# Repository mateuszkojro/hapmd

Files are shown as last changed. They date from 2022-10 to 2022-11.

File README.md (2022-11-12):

# hapmd
Horizontal antenna pattern measurement device

# The logic representation of HAPMD 


# [Mocked output from HAPMD](doc/2022_11_07_10_24_30_apm_plot.pdf)

# Repository contains:
  - 3d models of 
    - rotor under Transmitter
    - silent chamber
    with documentation how to print and assemble parts
  - list of components easily obtainable ih every hardware store 
  - Arduino-Pc connector package; script controlling rotation of Transmiter
  - Script synchronizing actions of Hameg device and Arduino
  - Result visualizer
  - Documentation with how to perform
    - Repository set-up
    - Physical parts of device set-up
    - Run the experiment
    - Analyze and interpret results

# Suppliers of components:
  ### rs components
  ### farnel
  ### conrad 
  ### botland

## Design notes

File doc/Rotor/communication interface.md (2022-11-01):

# Communication standard between Python API and C++ arduino software
| *command* | *shorthand* | *arguments* | *answer* | *response time* | *example* | *description* |
|:---:|:---:|:---:|:---:|:---:|:---:|:---:|
| get angle | get | --- |  float | short | req:'get'  resp:'-12.2' | angle hold by rotor |
| set angle | set | float |  float | long | req:'set-12.4'  resp:'-12.2' | the actual motor might not be able to turn to requested angle, the true angle set by rotor is returned |
| connection status | con | --- | str | short | req:'con'  resp:'ok' | check connection state |
|  override angle | ovr | float |  float | short |  req:'ovr12.3'  resp:'12.3'  | override angle in rotor memory |

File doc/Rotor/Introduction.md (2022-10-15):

# Rotor 
Simple device driven by arduino board, enables ether transmitter or receiver to be rotated around it's center of rotation. The goal of rotor is to rotate antenna with great precision, and repeatability. The speed of rotation does not matter, neither does time to response, error tolerance is around 1°.

Biggest obstacles when designing the rotor shaft are:
- concentric cable to witch antenna is connected, this cable is not flexible thus presents big resistance when antena is turned against it. This resistance is multiplied by height of rotor shaft.
- slack between parts

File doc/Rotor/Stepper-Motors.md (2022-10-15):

# Stepper motors

A stepper motor consists of two main parts, a rotor and a stator. The rotor is the part of the motor that actually spins and provides work. The stator is the stationary part of the motor that houses the rotor. In a stepper motor, the rotor is a permanent magnet. The stator consists of multiple coils that act as electromagnets when an electrical current is passed through them. The electromagnetic coil will cause the rotor to align with it when charged. The rotor is propelled by alternating which coil has a current running through it. 

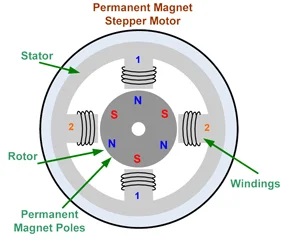
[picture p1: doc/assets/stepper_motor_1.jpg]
stepper_motor


When there is no current send to the motor, the steppers firmly hold their position. Stepper motors can also rotate without limits and change direction based on the polarity provided.

Most stepper motors come with four or six wires, stepper motors have tow coils ie, two circuits that makes 4 wires, additional two are connected to centers of the coils, therefore can be omitted. 

# Two unnecessary wires

Provided unnamed steper motors are 6-wire ones, since additional "center of the coil" wires are not needed there's a need to figure out witch is witch.

Between the wires connected to the same phase slight resistance is present, we can use that to label wires connected to same circuits. 
Between "middle of the col" wire and rest of the same circuit wires resistance will be smaller than  between other two. 

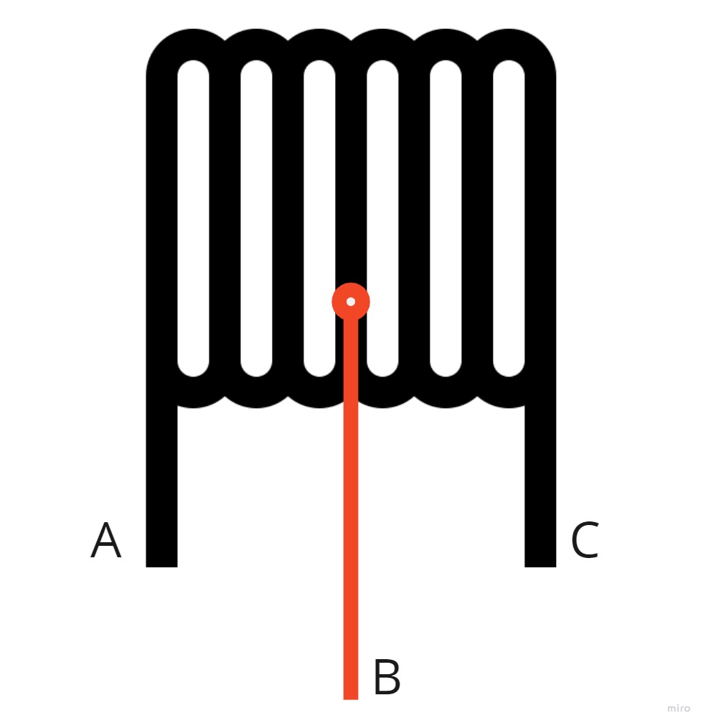
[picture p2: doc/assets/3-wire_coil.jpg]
3-wire-coil


Resistance present between wires A-C will be than between A-B or B-C, therefore wire B is the unnecessary "middle of the coil" wire.

Unnamed steper motors have 6 wires, left to right:
| Id | Color  | Abbreviation | Phase |  Function |
|:--:|:---:|:---:|:-----:|:---:|
| 1  | Orange | O | B |  End wire |
| 2  | White  | W | A | Middle Wire |
| 3  | Yellow | Y | A |  End wire |
| 4  | Brown  | Br | B |  End wire |
| 5  | Black  | Bl | B | Middle Wire |
| 6  |  Red | R | A |  End wire |

Resistances between each of them in [MΩ]:

| wire\wire | O  | W | Y  | Br | Bl | R  |
|:---:|:--:|:-:|:--:|:--:|:--:|:--:|
| O | 0  | - | -  | 15 | 9  | -  |
| W | -  | 0 | 9  | -  | -  | 9  |
| Y | -  | 9 | 0  | -  | -  | 15 |
| Br | 15 | - | -  | 0  | 9  | -  |
| Bl | 9  | - | -  | 9  | 0  | -  |
| R | -  | 9 | 15 | -  | -  | 0  |

# A4988 Driver

[Official Documentation](https://www.pololu.com/file/0J450/a4988_DMOS_microstepping_driver_with_translator.pdf)

## Pin design:

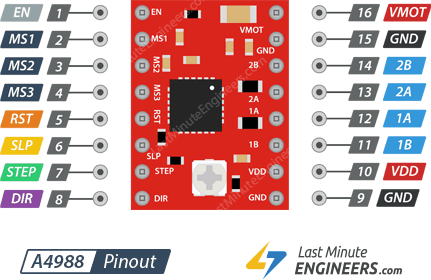
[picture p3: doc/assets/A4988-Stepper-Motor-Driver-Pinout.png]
pin_design


## Pin Modes 
| J1 | Pin  | Mode | J2 | Pin  | Mode |
|:--:|:----:|:---:|:--:|:----:|:---:|
| 1  |  EN  | Enable | 16 | VMOT | Power Voltage |
| 2  | MS1  | Micro-step setting | 15 | GND  | Ground |
| 3  | MS2  | Micro-step setting | 14 |  2B  | Phase B |
| 4  | MS3  | Micro-step setting | 13 |  2A  | Phase A |
| 5  | RST  | Reset | 12 |  1A  | Phase A |
| 6  | SLP  | Sleep | 11 |  1B  | Phase B |
| 7  | STEP | Step | 10 | VDD  | Logic voltage |
| 8  | DIR  |  Direction input | 9  | GND  | Ground |

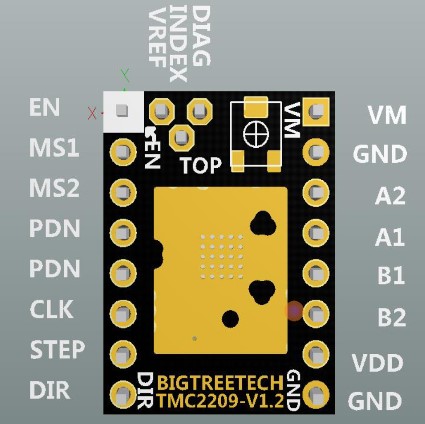
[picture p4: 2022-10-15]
doc/assets/TMC2209_pin_design.jpg

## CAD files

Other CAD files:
models/Antennas_YnVzaW5lc3M6bXllZHU2MTk2IzIwMjIwNzI3NTQyNDQ1OTA2/Bottom corner_c5e7e790-342b-49d1-b435-a4cb2366abbe.f3d
models/Antennas_YnVzaW5lc3M6bXllZHU2MTk2IzIwMjIwNzI3NTQyNDQ1OTA2/Full Box Assembly_c8e0fb49-985c-4273-afc7-069acc2b1639.f3d
models/Antennas_YnVzaW5lc3M6bXllZHU2MTk2IzIwMjIwNzI3NTQyNDQ1OTA2/Nail_13ead31a-0b00-4445-9a30-be61a9d9af6d.f3d
models/Antennas_YnVzaW5lc3M6bXllZHU2MTk2IzIwMjIwNzI3NTQyNDQ1OTA2/Rod_Stand_antenna_holder_0a369a4e-08f0-4d4c-95f8-d1debb118e1a.f3d
models/Antennas_YnVzaW5lc3M6bXllZHU2MTk2IzIwMjIwNzI3NTQyNDQ1OTA2/Rotor Shaft_825ccad0-c9c1-482b-9b45-a1c8e1959537.f3d
models/Antennas_YnVzaW5lc3M6bXllZHU2MTk2IzIwMjIwNzI3NTQyNDQ1OTA2/Stator_e84299ef-5bad-46b8-848a-41ee6117f2a9.f3d
models/Antennas_YnVzaW5lc3M6bXllZHU2MTk2IzIwMjIwNzI3NTQyNDQ1OTA2/Top corner_ed42d94d-94fe-402c-95f1-07cb350324a0.f3d
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

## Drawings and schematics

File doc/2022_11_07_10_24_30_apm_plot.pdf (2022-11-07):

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

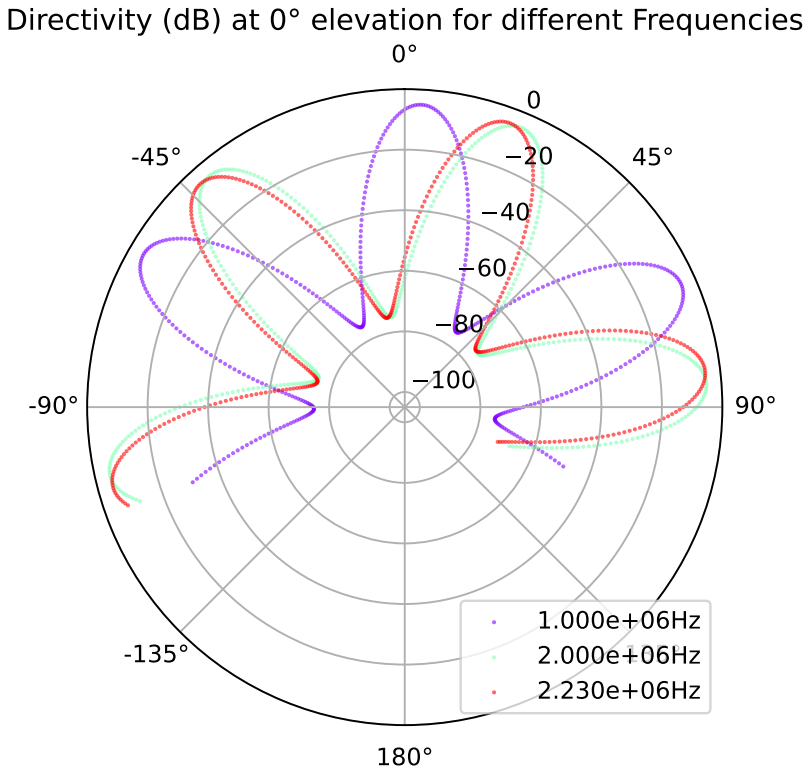
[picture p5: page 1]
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

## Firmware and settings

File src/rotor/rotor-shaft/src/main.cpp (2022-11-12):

// #include <Arduino.h>
// #include "A4988.h"

// float step_angle = 360.f / 200.f; // default change in angle, when rotated by one step
// float current_angle = 0;
// A4988 stepper_motor(6, 8);
// String response;
// String message;
// String command;
// String message_copy;
// String handle_set(const String &message)
// {
//   auto new_angle = message.toFloat();
//   int no_steps_to_move = round((new_angle - current_angle) / step_angle);
//   if (no_steps_to_move < 0)
//   {
//     stepper_motor.SetDirection(A4988::Direction::CCW);
//   }
//   else
//   {
//     stepper_motor.SetDirection(A4988::Direction::CW);
//   }
//   stepper_motor.Step(abs(no_steps_to_move));

//   current_angle = current_angle + (no_steps_to_move * step_angle);

//   return String(no_steps_to_move);
// }
// void setup()
// {
//   Serial.begin(115200);
//   Serial.print("arduino_ok\n");
// }
// void loop()
// {
//   message = Serial.readStringUntil('\n');
//   while (message.length() == 0)
//   {
//     message = Serial.readStringUntil('\n');
//     message.trim(); // deletes all leading and trailing whitespaces
//     message.replace("\n", "");
//   }

//   message_copy = message;

//   command = message.substring(0, 3);

//   if (command == "get")
//   {
//     response = String(current_angle) + "";
//   }
//   else if (command == "set")
//   {
//     response = handle_set(message.substring(3));
//   }
//   else if (command == "con")
//   {
//     response = "arduino_ok";
//   }
//   else if (command == "ovr")
//   {
//     current_angle = message.toFloat();
//     response = String(current_angle);
//   }
//   else
//   {
//     response = String("failed to intepret the input>" + message_copy + "<");
//   }
//   Serial.print(response + "\n");
// }

#include <Arduino.h>
const int dirPin = 8;
const int stepPin = 6;
const int stepsPerRevolution = 200;

void setup()
{
  // Declare pins as Outputs
  pinMode(stepPin, OUTPUT);
  pinMode(dirPin, OUTPUT);
}
void loop()
{
  // Set motor direction clockwise
  digitalWrite(dirPin, HIGH);

  // Spin motor slowly
  for (int x = 0; x < stepsPerRevolution; x++)
  {
    digitalWrite(stepPin, HIGH);
    delayMicroseconds(2000);
    digitalWrite(stepPin, LOW);
    delayMicroseconds(2000);
  }
  delay(1000); // Wait a second

  // Set motor direction counterclockwise
  digitalWrite(dirPin, LOW);

  // Spin motor quickly
  for (int x = 0; x < stepsPerRevolution; x++)
  {
    digitalWrite(stepPin, HIGH);
    delayMicroseconds(1000);
    digitalWrite(stepPin, LOW);
    delayMicroseconds(1000);
  }
  delay(1000); // Wait a second
}

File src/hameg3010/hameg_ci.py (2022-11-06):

from typing import Union
from device import Device
from device_mock import DeviceMock

def hameg_console_loop(hameg_handle:Union[Device,DeviceMock]):
    while True:
        command = input("hameg> ")
        command = command.casefold()
        command = command.replace(" ","")
        if command in ("quit", 'q'):
            return
        else:
            resp = hameg_handle.send_await_resp(command)
            print(f"response: {resp[1]}")
            print(
                f"errors:   {hameg_handle.send_await_resp('SYSTem:ERRor:ALL?')[1][2:-1]}"
            )
            
if __name__ == "__main__":
    print(
        """
        
 /$$   /$$                                                    /$$$$$$  /$$$$$$
| $$  | $$                                                   /$$__  $$|_  $$_/
| $$  | $$  /$$$$$$  /$$$$$$/$$$$   /$$$$$$   /$$$$$$       | $$  \__/  | $$  
| $$$$$$$$ |____  $$| $$_  $$_  $$ /$$__  $$ /$$__  $$      | $$        | $$  
| $$__  $$  /$$$$$$$| $$ \ $$ \ $$| $$$$$$$$| $$  \ $$      | $$        | $$  
| $$  | $$ /$$__  $$| $$ | $$ | $$| $$_____/| $$  | $$      | $$    $$  | $$  
| $$  | $$|  $$$$$$$| $$ | $$ | $$|  $$$$$$$|  $$$$$$$      |  $$$$$$/ /$$$$$$
|__/  |__/ \_______/|__/ |__/ |__/ \_______/ \____  $$       \______/ |______/
                                             /$$  \ $$                        
                                            |  $$$$$$/                        
                                             \______/                         """
    )

    hameg_device_handle = DeviceMock.connect_using_vid_pid(
        idVendor=0x0403, idProduct=0xED72
    )

    print(
        f"""
Connected to Hameg device
IDN              : {hameg_device_handle.send_await_resp("*IDN?")[1][2:-1]}
Software Version : {hameg_device_handle.send_await_resp("SYSTem:SOFTware?")[1][2:-1]}
Hardware Version : {hameg_device_handle.send_await_resp("SYSTem:HARDware?")[1][2:-1]}
          """
    )
    # clean errors
    hameg_device_handle.send_await_resp("SYSTem:ERRor:ALL?")
    
    hameg_console_loop(hameg_device_handle)

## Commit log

2022-09-14 rotor innit
2022-10-15 documentation and models update
    [Bottom corner_c5e7e790-342b-49d1-b435-a4cb2366abbe.f3d, Full Box Assembly_c8e0fb49-985c-4273-afc7-069acc2b1639.f3d, Nail_13ead31a-0b00-4445-9a30-be61a9d9af6d.f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]
2022-10-18 updated the models
    [Full Box Assembly_c8e0fb49-985c-4273-afc7-069acc2b1639.f3d, Rod_Stand_antenna_holder_0a369a4e-08f0-4d4c-95f8-d1debb118e1a.f3d]
2022-10-18 moved rotor src
2022-10-18 hameg connector
2022-10-23 added dash as web gui framework
2022-10-25 start stop button css
2022-10-25 added start stop button
2022-10-26 introduction of button measurement time logic
2022-10-29 documentation to Rotor CI
2022-10-29 arduino command handling
2022-10-29 rotor CI up to spec still some bugs tho
2022-10-30 working Rotor CI
2022-10-31 moved A4988 class outside main rotor file
2022-11-01 mock for hameg device
2022-11-01 fixed below zero angle bug
    [main.cpp]
2022-11-01 arduino connector mock for accelerated development
2022-11-06 hameg device debugging
2022-11-06 better mock, more closely approximating actual hameg device
2022-11-06 device class mock, basically hameg_mock
2022-11-06 added device mock to hameg ci
2022-11-06 colors for rotor_ci
2022-11-06 better print and loading config from file
2022-11-06 antenna holder
2022-11-07 example measurement config with results
    [2022_11_07_10_24_30_apm.csv]
2022-11-07 deleted unused files
    [2022_11_07_10_24_30_apm.csv]
2022-11-12 using arduino device instead of mock
